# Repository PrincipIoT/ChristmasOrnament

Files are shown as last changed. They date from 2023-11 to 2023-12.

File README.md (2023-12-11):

# PCB Christmas Ornament
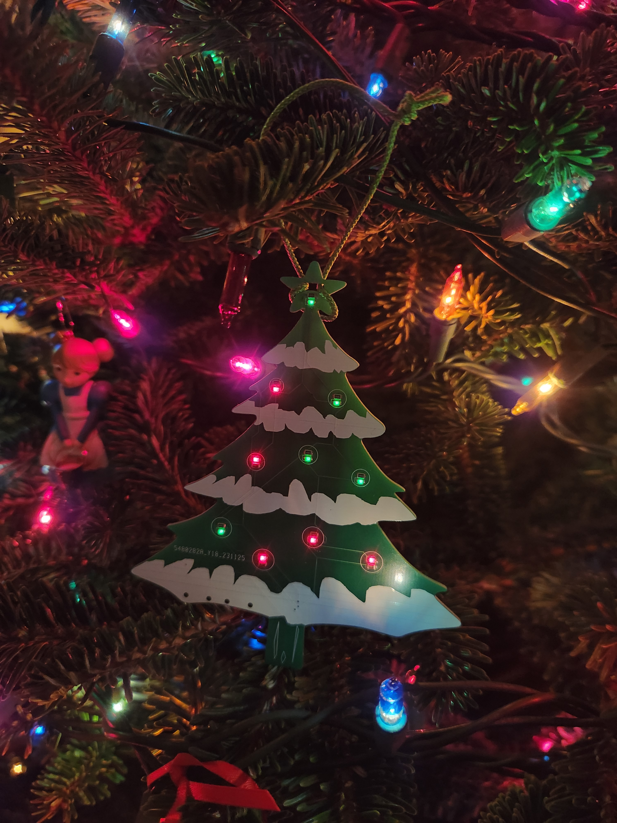
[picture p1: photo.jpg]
cover photo


These are the design files for PrincipIoT's Christmas Tree PCB Ornament.

This repository includes the KiCAD design files, schematic, and bill of materials in the `OrnamentSCH` folder, and software in the `OrnamentCode` file. The hex file for the compiled firmware is available on the releases page.

These ornaments are available to purchase on [Etsy](https://principiot.etsy.com/listing/1627174457) and [Tindie](https://www.tindie.com/products/principiot/led-christmas-tree-ornament-twinkles/)

# Flashing
To flash the firmware to a board, use `avrdude` (it's included in the Arduino IDE). Make sure to have the [ATTinyCore](https://github.com/SpenceKonde/ATTinyCore) installed as well.

`avrdude -Cavrdude.conf -v -pattiny25 -cusbasp -e -Uefuse:w:0xFF:m -Uhfuse:w:0b11010111:m -Ulfuse:w:0xE2:m -Uflash:w:fwv1.0.hex:i`

For the `avrdude.conf` file, use the default provided by the Arduino IDE, except set the `default_bitclock` setting to 5: `default_bitclock = 5;`

# Licensing
All work is copyright PrincipIoT LLC 2023. Design files are released under the respective licenses in each folder.

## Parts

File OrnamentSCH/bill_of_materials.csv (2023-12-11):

Description | Part# | Link | QTY per unit | Identifier
RED LED @ 2V 5mA View Angle 130 Deg Wavelength 631nm | 160-1830-1-ND | https://www.digikey.com/en/products/detail/liteon/LTST-C193KRKT-5A/2356244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 | 5 | D10, D8, D6, D4, D2
GREEN LED @ 3V 5mA View Angle 140 Deg Wavelength 530nm | 404-1286-1-ND | https://www.digikey.com/en/products/detail/stanley-electric-co/THG1111C-0005-TR/8544260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 | 5 | D9, D7, D5, D3, D1
ATtiny25-20SUR | ATTINY25V-10SSU-ND | https://www.digikey.com/en/products/detail/microchip-technology/ATTINY25V-10SSU/1886243 | 1 | U1
Slide Switch | 401-1999-1-ND | https://www.digikey.com/en/products/detail/c-k/JS102011SAQN/1640095?s=N4IgTCBcDaICwAYCMBaJBOTaUDkAiIAugL5A | 2 | SW1,SW2
4.7uF 0603 Cap | 1276-1045-1-ND | https://www.digikey.com/en/products/detail/samsung-electro-mechanics/CL10A475KQ8NNNC/3886703 | 1 | C1
560Ω SMD Resister 0603 | 118-CR0603-FX-5600ELFCT-ND | https://www.digikey.com/en/products/detail/bourns-inc/CR0603-FX-5600ELF/3784091 | 5 | R9, R7, R5, R3, R1
180Ω SMD Resister 0603 | 311-180GRCT-ND | https://www.digikey.com/en/products/detail/yageo/RC0603JR-07180RL/726722 | 5 | R10, R8, R6, R4, R2
AAA Battery Holder |  | https://www.amazon.com/LAMPVPATH-Battery-Holder-Leads-Wires/dp/B07CST9HKD | 1

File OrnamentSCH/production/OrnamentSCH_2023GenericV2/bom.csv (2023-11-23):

Designator | Footprint | Quantity | Value | LCSC Part #
C1 | 0603 | 1 | 4.7uF
C2 | 0603 | 1 | .1uF
D1, D3, D5, D7, D9 | 0603 | 5 | WHITE
D10, D2, D4, D6, D8 | 0603 | 5 | RED
J1 | PowerPad | 1 | Conn_01x02_Pin
J2 | SMDHeader_1x06 | 1 | Conn_01x06_Pin
R1, R3, R5, R7, R9 | 0603 | 5 | 10Ω
R10, R2, R4, R6, R8 | 0603 | 5 | 100Ω
SW1, SW2 | JS102011SAQN | 2 | SW_SPDT
U1 | SOIC-8W_5.3x5.3mm_P1.27mm | 1 | ATtiny25-20S

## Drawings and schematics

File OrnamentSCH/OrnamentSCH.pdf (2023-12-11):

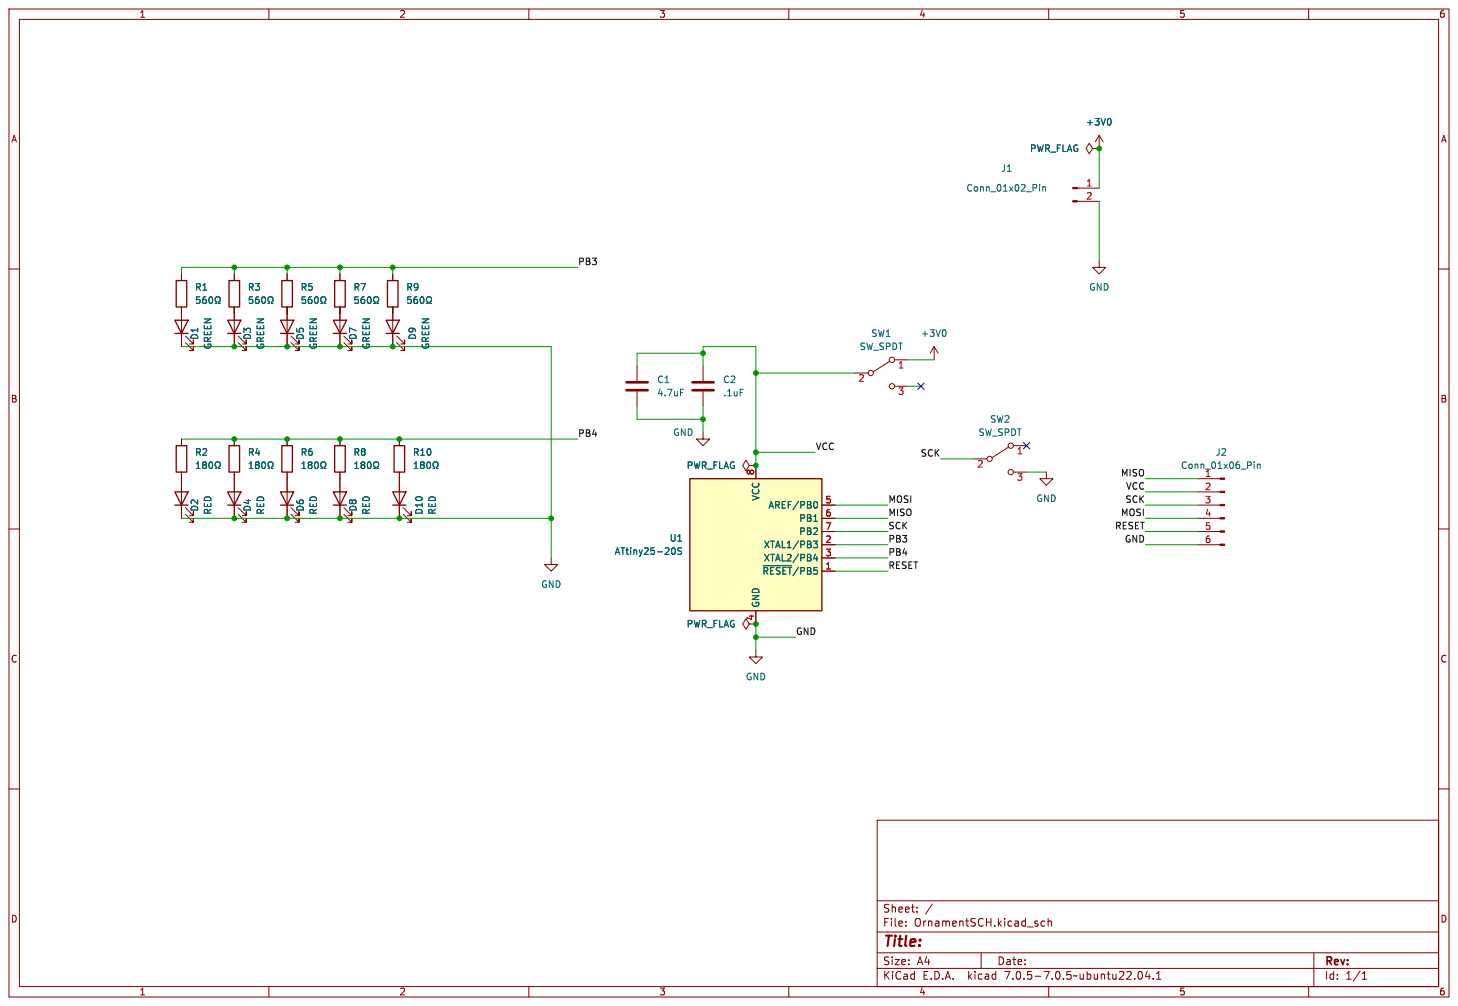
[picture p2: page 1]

SCK RESET MOSI GND D9 GREEN

Id: 1/1 Title: File: OrnamentSCH.kicad_sch Sheet: / GND

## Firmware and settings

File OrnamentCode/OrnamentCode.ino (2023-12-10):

#include <avr/interrupt.h>
#include <avr/sleep.h>

/*
 * File: OrnamentCode.ino
 * Lukas Severinghaus, PrincipIoT LLC
 * Dec 10, 2023
 * Rev 1
 * Software for the PrincipIoT PCB Christmas Tree Ornament.  
*/

#define TIMER_PERIOD 60*60*1000
volatile bool timer_enabled = false;
volatile long timer_end = 0;

ISR(PCINT0_vect){
  if((PINB >> 2) & 1){
    // Timer not enabled
    timer_enabled = false;
  }else{
    // Timer enabled
    timer_enabled = true;
    timer_end = millis() + TIMER_PERIOD;
  }
}

void setup() {
  DDRB = 0b00011000; // Set 4,3 to out, 2 to input
  PORTB |= 0b00000100; // Pullup on pin 2

  // Disable ADC and set pin change interrupt
  ADCSRA = 0;
  GIMSK = 0b00100000; 
  PCMSK = 0b00000100;  
  if(!((PINB >> 2) & 1)){
    timer_enabled = true;
    timer_end = millis() + TIMER_PERIOD;
  }
}


#define MAX 1000
int red_index = (int) MAX/3;
int red_direction = 1;
int green_index = 0;
int green_direction = 1;

void loop() { 
  increment_green();
  increment_red();
  if(timer_enabled && millis() > timer_end){
    timer_enabled = false;
    go_to_sleep();
  }
}

void go_to_sleep(){
  digitalWrite(3, 0);
  digitalWrite(4, 0);
  sleep_enable();
  set_sleep_mode(SLEEP_MODE_PWR_DOWN);  
  sleep_cpu(); 
  return;
  
  MCUCR |= 00110000; // Set SE bit and set mode to power down
  sleep_cpu(); // Execute sleep command
  MCUCR ^= 00100000; // Clear SE bit, after exiting sleep
}

void increment_green(){
  if(green_index == MAX){
    green_direction = -1;
  }else if(green_index == 0){
    green_direction = 1;
  }
  PORTB |= 1<<3;
  delayMicroseconds(green_index);
  PORTB &= ~(1<<3);
  delayMicroseconds(MAX-green_index);
  green_index += green_direction;  
}

void increment_red(){
  if(red_index == MAX){
    red_direction = -1;
  }else if(red_index == 0){
    red_direction = 1;
  }
  PORTB |= 1<<4;
  delayMicroseconds(red_index);
  PORTB &= ~(1<<4);
  delayMicroseconds(MAX-red_index);
  red_index += red_direction;
}

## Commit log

2023-11-15 Schematic and Component Selection
    [OrnamentSCH.kicad_pcb, OrnamentSCH.kicad_sch]
2023-11-15 Update with fix of layout and use of net labels
    [OrnamentSCH.kicad_sch]
2023-11-15 Part for number for slide switch
    [OrnamentSCH.kicad_sch]
2023-11-16 Component selection and schematic updated
    [OrnamentSCH.kicad_sch]
2023-11-16 Added footprints
    [OrnamentSCH.kicad_sch]
2023-11-16 Changed the switch from SP_SPST to SP_SPDT and made footprint for switch
    [OrnamentSCH.kicad_sch]
2023-11-16 added switch
    [OrnamentSCH.kicad_sch]
2023-11-17 Started PCB Design
    [OrnamentSCH.kicad_pcb, OrnamentSCH.kicad_sch]
2023-11-18 PCB Designed
    [OrnamentSCH.kicad_pcb, OrnamentSCH.kicad_sch]
2023-11-21 Updated Footrpints and routed PCB
    [OrnamentSCH.dsn, OrnamentSCH.kicad_pcb, OrnamentSCH.kicad_sch]
2023-11-21 Updated footrpint for headers and re routed pcb
    [OrnamentSCH.dsn, OrnamentSCH.kicad_pcb]
2023-11-22 Fixed some errors
    [OrnamentSCH.kicad_pcb]
2023-11-22 Routed and down to silkscreen warnings and two errors
    [OrnamentSCH.dsn, OrnamentSCH.kicad_pcb]
2023-11-22 fixed footprint and updated PCB
    [OrnamentSCH.kicad_pcb, OrnamentSCH.kicad_sch]
2023-11-22 I changed the orientation of the cap
    [OrnamentSCH.kicad_pcb, OrnamentSCH.kicad_sch]
2023-11-23 Message Added
    [OrnamentSCH.kicad_pcb]
2023-11-23 Made jlc pcb files
    [OrnamentSCH-B_Cu.gbr, OrnamentSCH-B_Mask.gbr, OrnamentSCH-B_Paste.gbr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]
2023-11-23 final changes before production
    [OrnamentSCH.kicad_pcb, bom.csv, designators.csv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]
2023-11-24 Fixed JLC prob
    [OrnamentSCH.kicad_pcb]
2023-11-24 Made 2 new files for the JLC submit
    [bom.csv, designators.csv, positions.csv]
2023-11-24 Removed Copper outline trace
    [OrnamentSCH.kicad_pcb, bom.csv, designators.csv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]
2023-11-27 updated schematic resister values
    [OrnamentSCH.kicad_sch]
2023-12-10 Prepare for release
    [OrnamentSCH-B_Cu.gbr, OrnamentSCH-B_Mask.gbr, OrnamentSCH-B_Paste.gbr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]
2023-12-11 Add readme and production files
    [bill_of_materials.csv]
